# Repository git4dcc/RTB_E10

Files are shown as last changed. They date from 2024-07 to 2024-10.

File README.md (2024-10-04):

# RTB_E10




This E10 module implements a 16 channel WS2811 emulator with compatible bus timing. The E10 may be cascaded with regular WS28xx chips. The number of LEDs is auto detected/configured (0-16). Optionally, the common LED voltage can be controlled over the bus as well.

<details>
<summary>See also</summary>

- [RTB_E13](https://github.com/git4dcc/RTB_E13)
- [RTB_E15](https://github.com/git4dcc/RTB_E15)

</details>

<details>
<summary>User Guides</summary>

- [User Guide - DE](https://rtb4dcc.de/ws2811_guide_de/)
- User Guide - EN

</details>

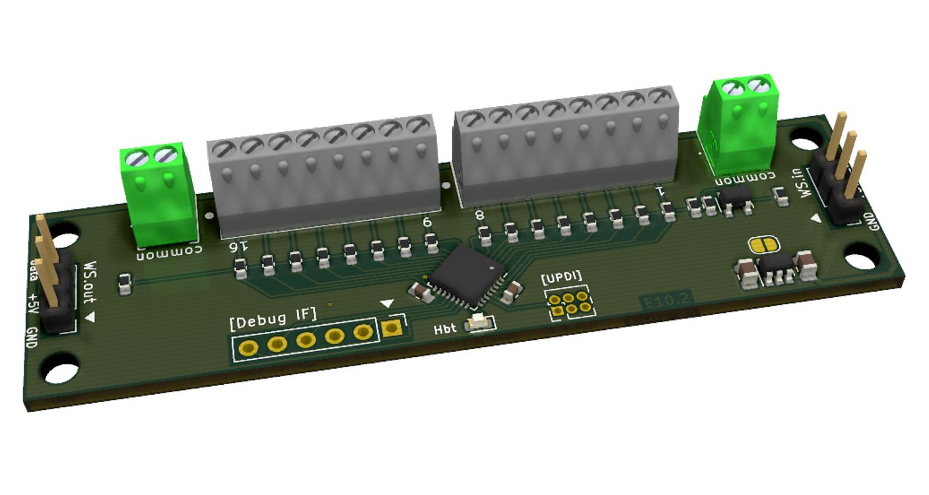
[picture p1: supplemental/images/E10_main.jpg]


The decoder has the following features,
- **Protocol**
  - WS2811 compatible timing
- **LED ports**
  - 0..16 channel output (auto detecting)
  - Software selectable common LED voltage (0 .. 5V)
  - Push/Pull output and can drive common anode or cathode
  - 256 step PWM (240Hz)
  - gamma correction (optional)
- firmware update via V24 debug interface

# Hardware
My current PCB layout uses SMD footprints with 0.5mm pitch and 0603 parts. Reflow soldering is my recommendation, but with some experience handsoldering is also possible.

The hardware allows either push or pull operation. Currently only the pull operation is implemented in the firmware. Should a usecase for push-operation arise, the firmware could be adapted.

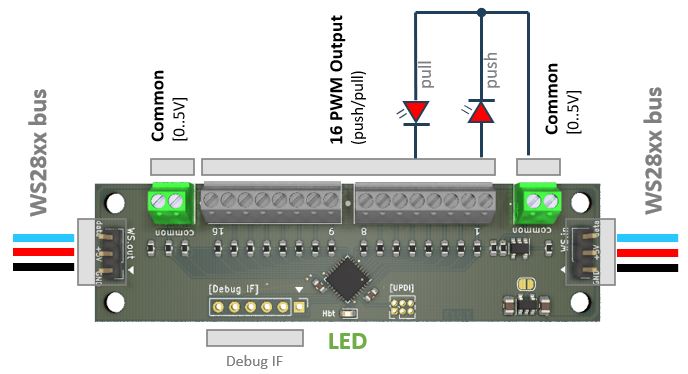
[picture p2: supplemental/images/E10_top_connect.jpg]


## PCB

- 2-layer PCB, FR4, 1.6mm
- CPU: AVR64DA32
- BUS: WS28xx
- LED: Push/Pull

## Kicad
[Schematic](doc/E10_schematic.pdf) | [Layout](doc/E10_layout.pdf) | [Gerber](gerber)

<details>
<summary>Dependency</summary>
<br>

:yellow_circle: Requires my Kicad project library [RTB_SamacSys](https://github.com/git4dcc/RTB_SamacSys) in the same directory tree.

</details>

## Firmware
Filename structure: { **pcb** }{ **code** }{ **version** }.hex

Example: **E10F0001**.hex

| | Description |
| --- | --- |
| **pcb** | Name of matching hardware (**E10**) |
| **code** | Type of code contained (**R**=rom, **B**=bootloader, **F**=flash, **U**=bld update, **P**=UPDI factory code) |
| **version** | Release version (**####**) |

[Firmware files](firmware)

## UPDI
The fuse settings as well as the P-code (E10Pxxxx.hex) has to be installed by using UPDI.<br>

<details>
<summary>Details</summary>

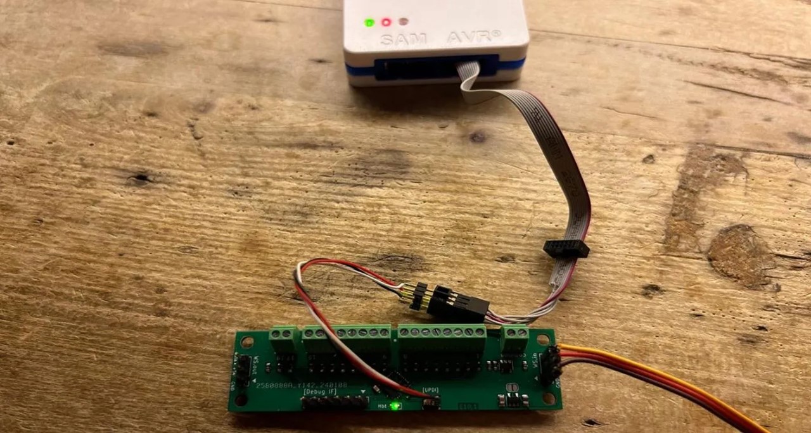
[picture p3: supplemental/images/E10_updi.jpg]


| Fuse Setting | P-Code Install |
| --- | --- |
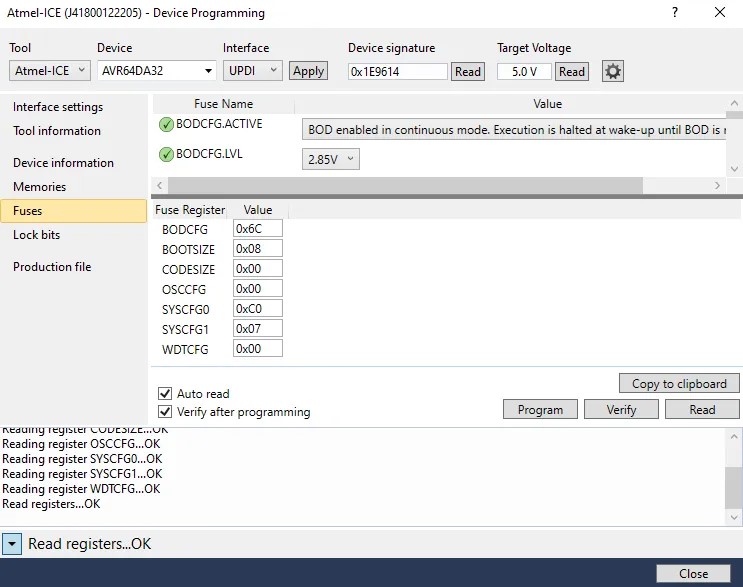
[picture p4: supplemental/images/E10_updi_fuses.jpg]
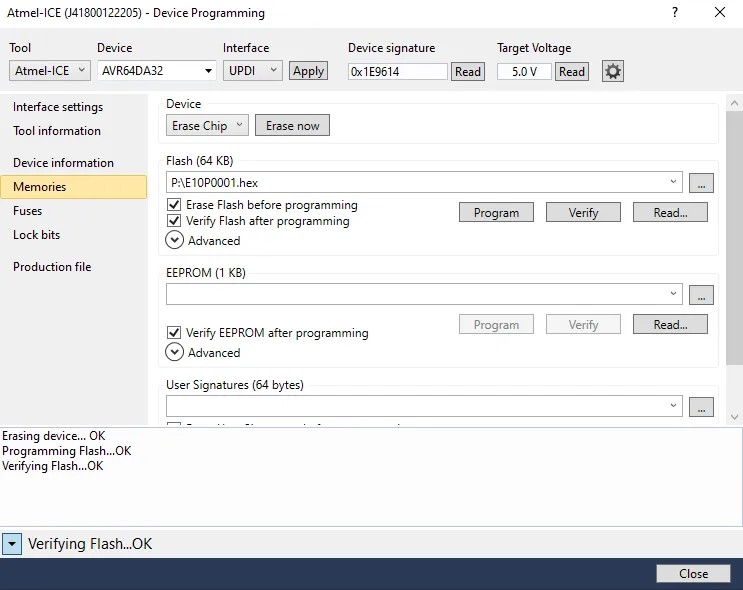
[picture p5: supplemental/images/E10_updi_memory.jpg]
|||

</details>

## Debug Interface
Subsequent code updates can be done via the built-in serial debug interface.<br>

<details>
<summary>Details</summary>

- connect the serial cable **(1Mb, 8N1, RTS/CTS)**
- press 'break' within the VT100 terminal to bump the module to console prompt
- upload the firmware file (E10Fxxxx.hex)
- for more details, refer to the 'User Guide'

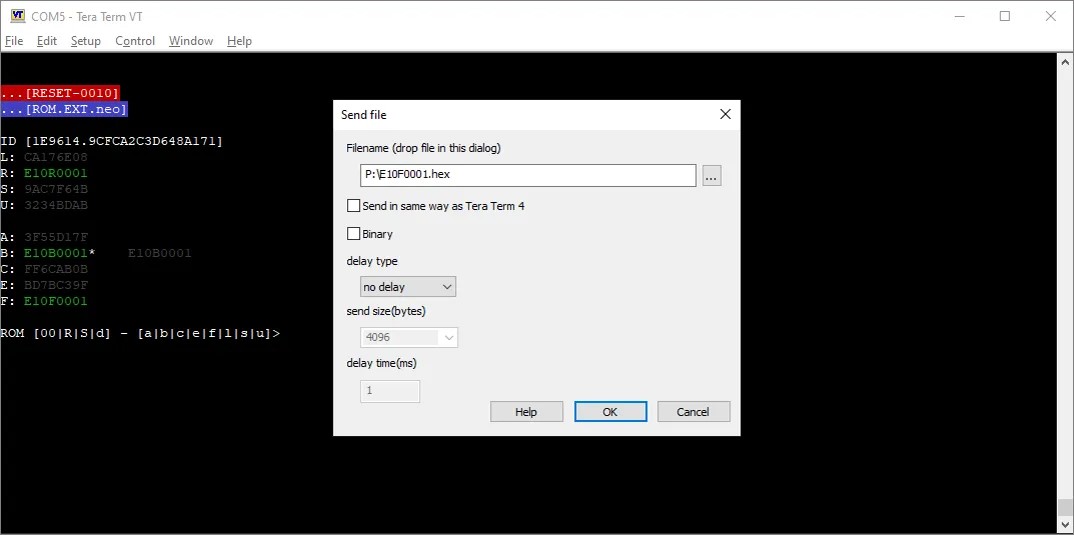
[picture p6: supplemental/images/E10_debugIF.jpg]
  
</details>

# Software
The LED common voltage must be sent as the first byte (virtual LED) over the bus followed by the intensity values for the individual LEDs.

```
Byte order:     {voltage} {led_0} ... {led_n}      //'n' being the number of configured LEDs
Led Voltage:    5V * {voltage} / 255
```

# Images
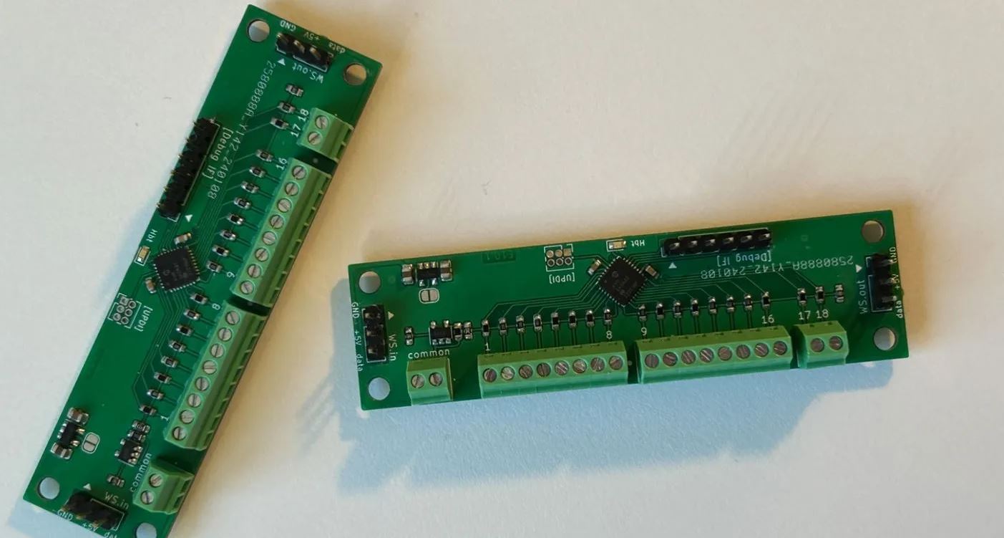
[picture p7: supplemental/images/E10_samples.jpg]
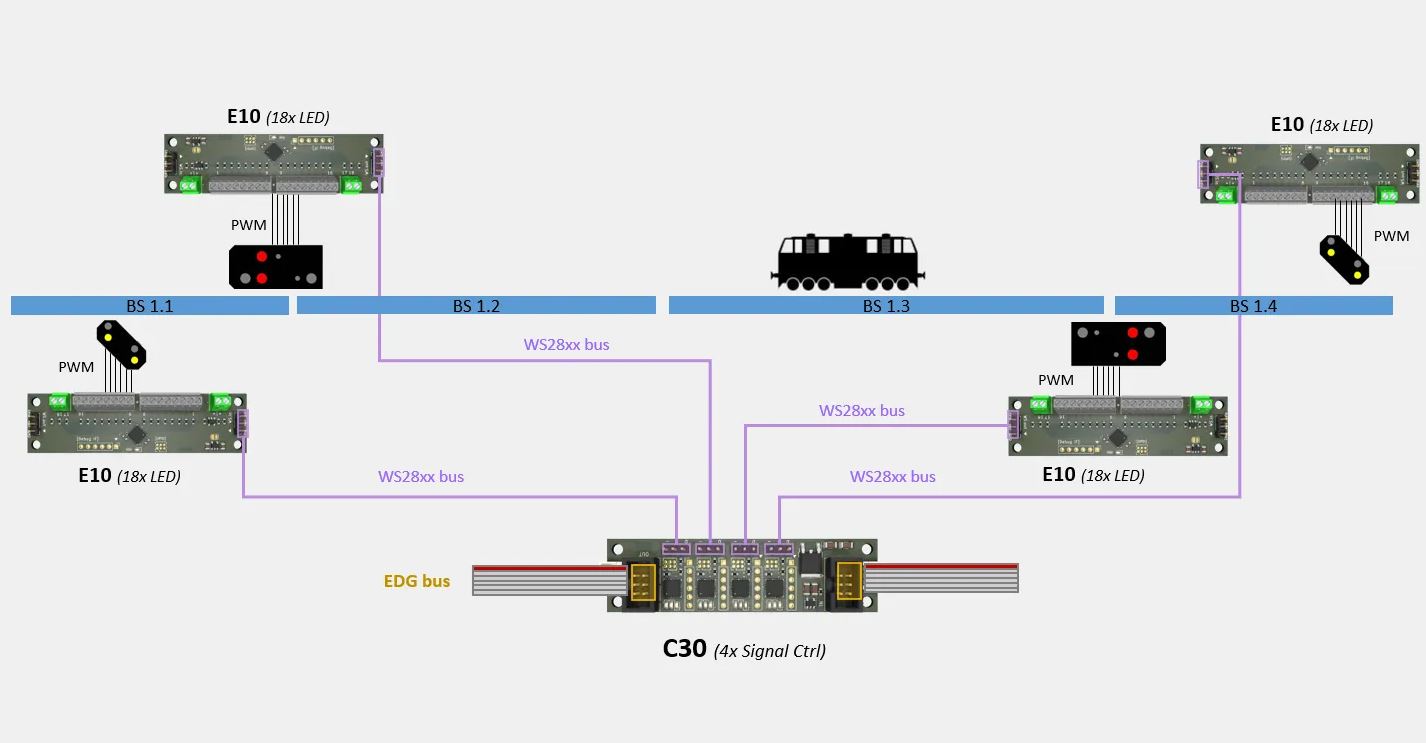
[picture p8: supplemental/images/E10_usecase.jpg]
 

This project is intended for hobby use only and is distributed in accordance with the Apache License 2.0 agreement.

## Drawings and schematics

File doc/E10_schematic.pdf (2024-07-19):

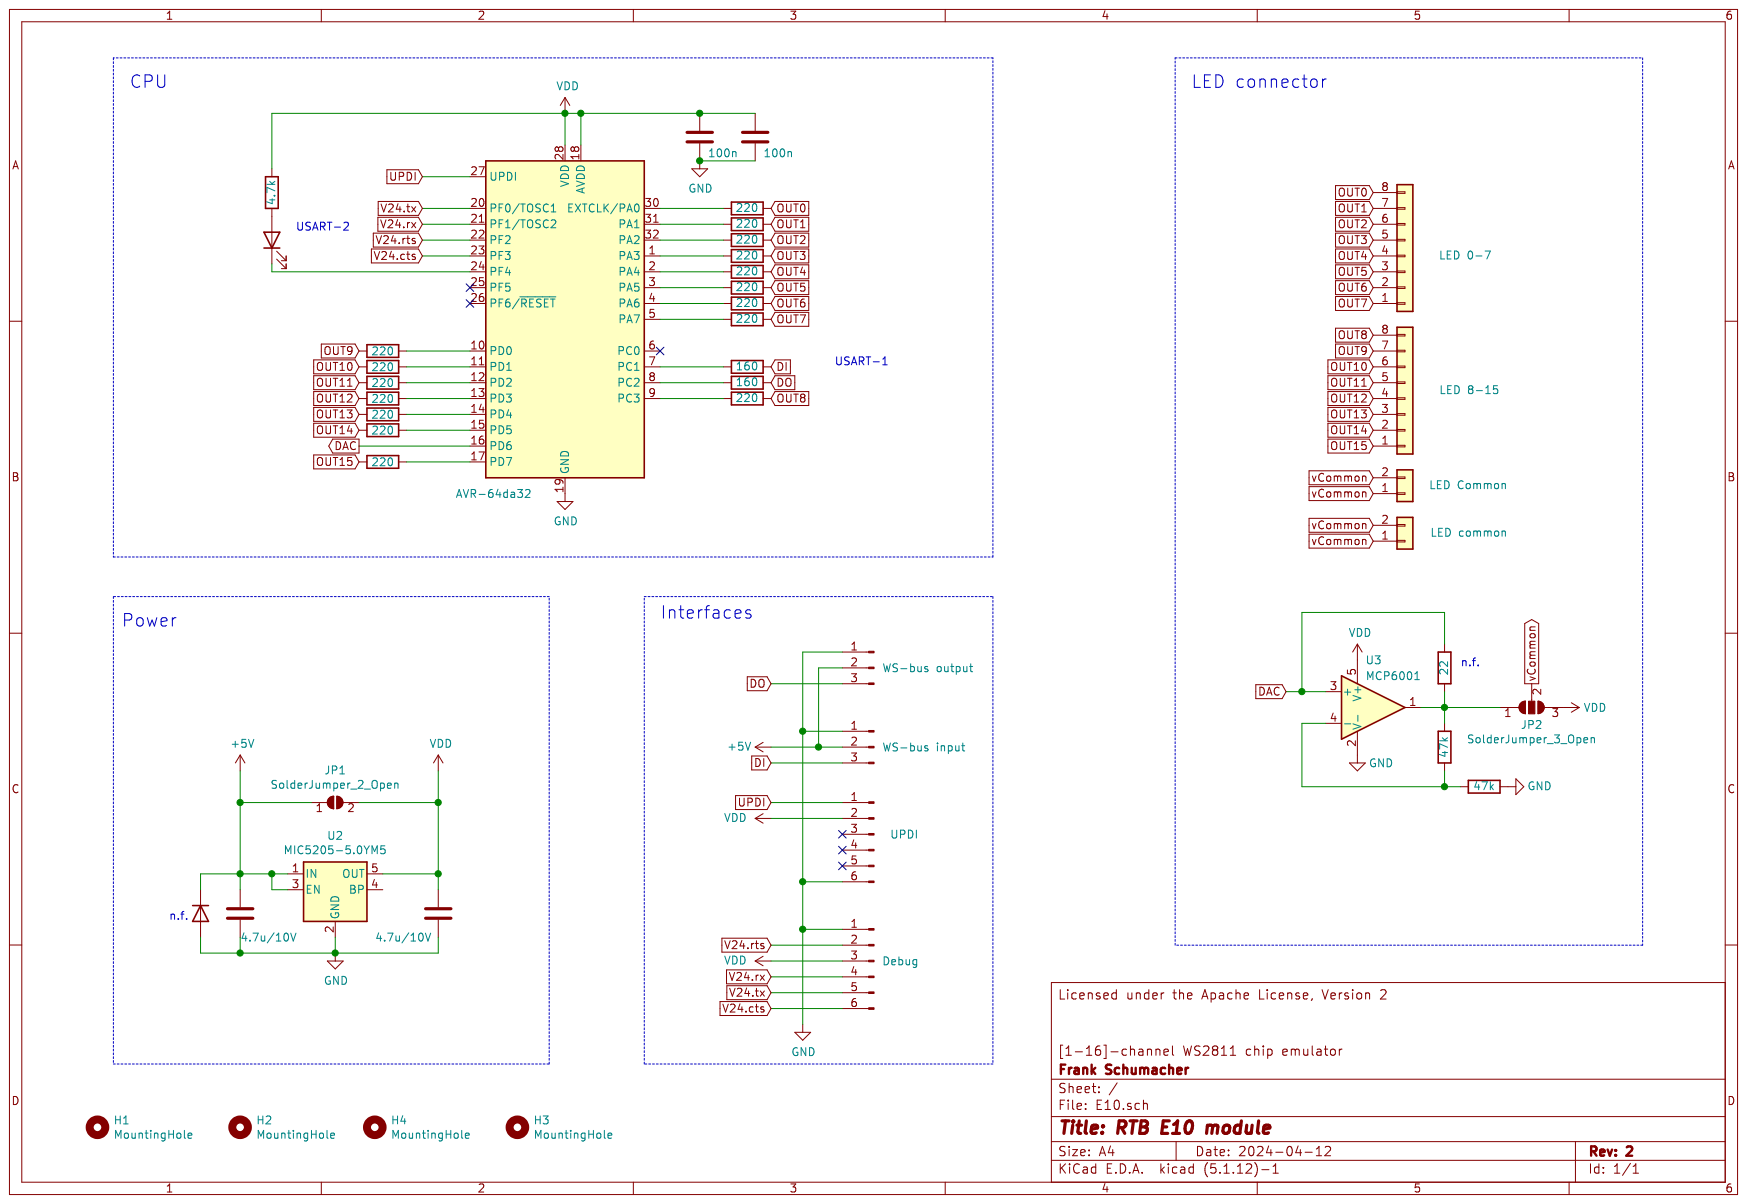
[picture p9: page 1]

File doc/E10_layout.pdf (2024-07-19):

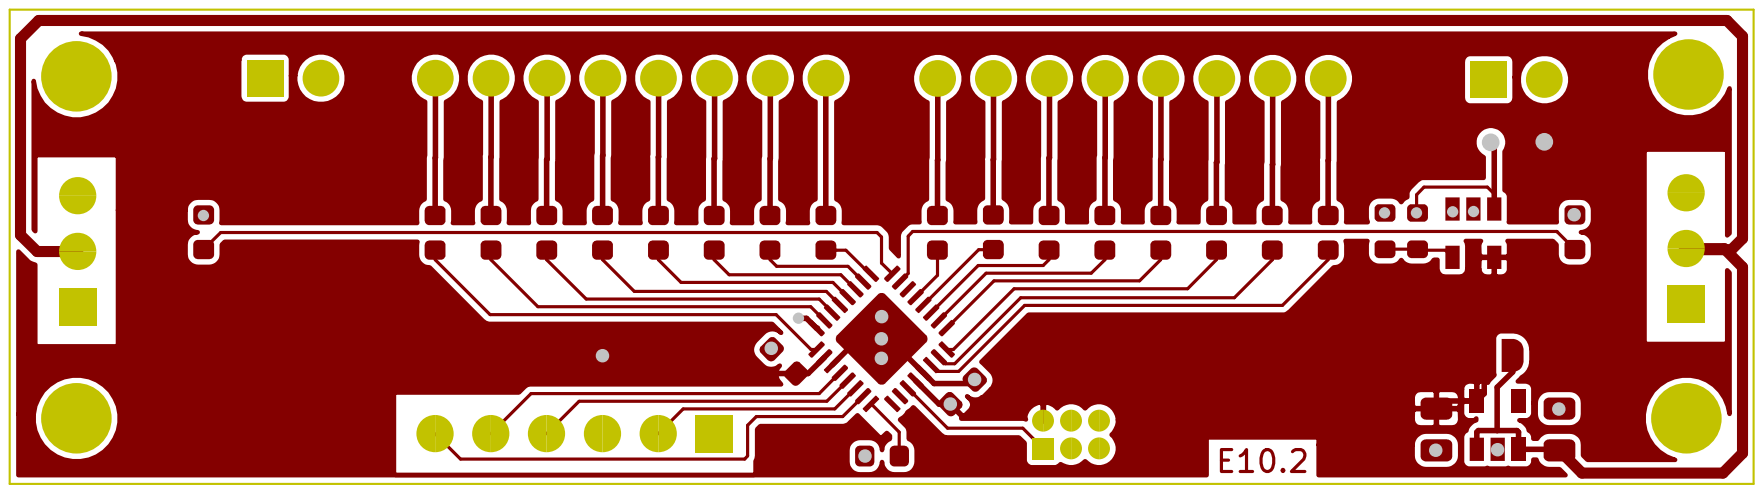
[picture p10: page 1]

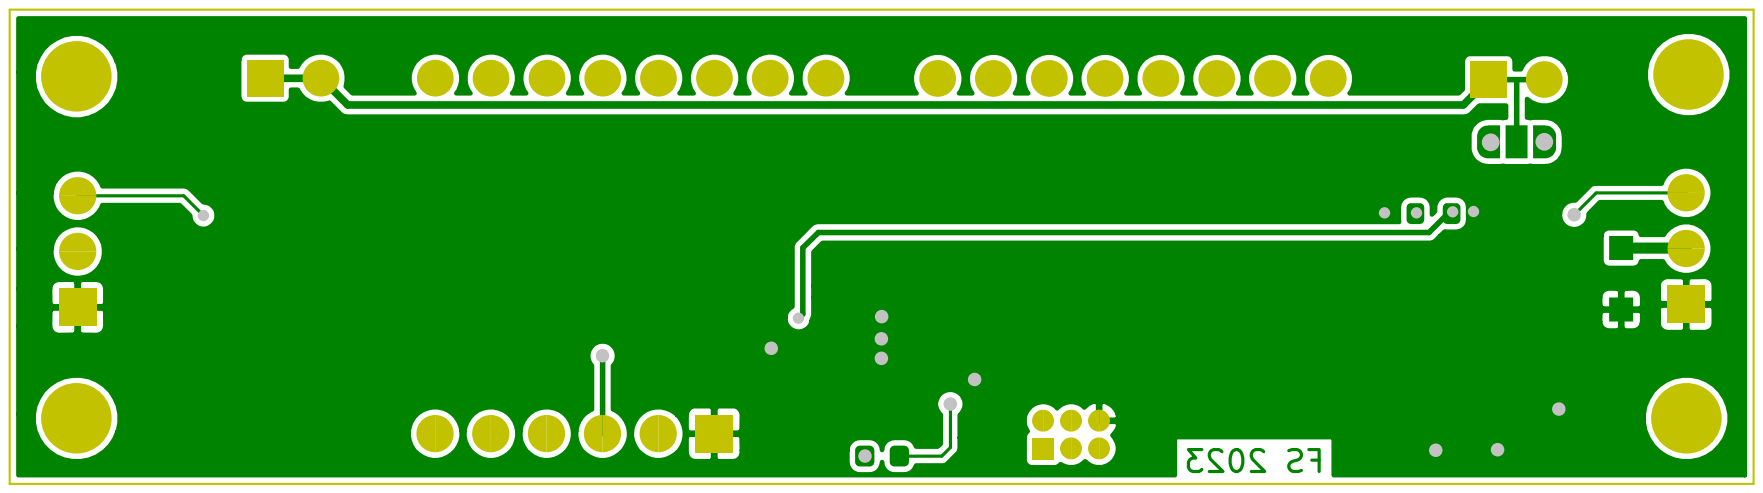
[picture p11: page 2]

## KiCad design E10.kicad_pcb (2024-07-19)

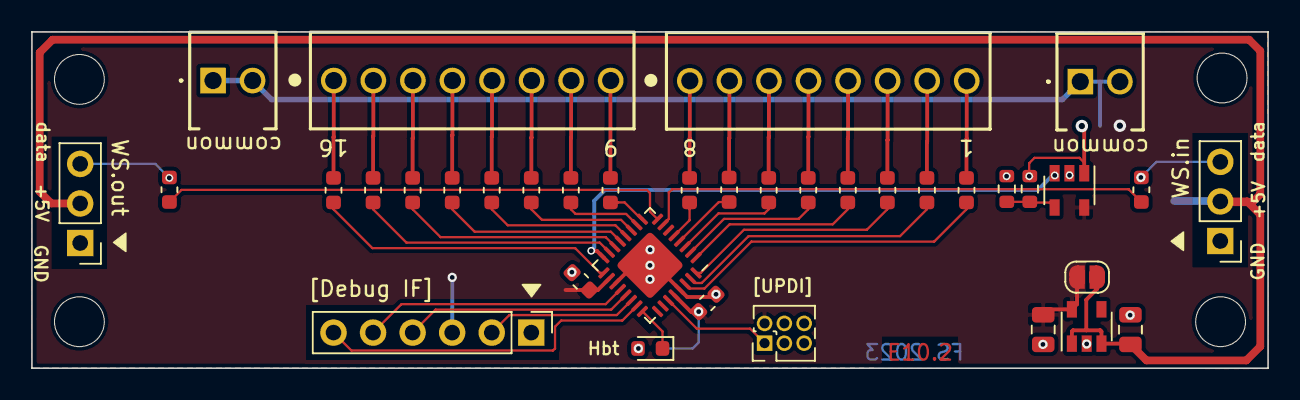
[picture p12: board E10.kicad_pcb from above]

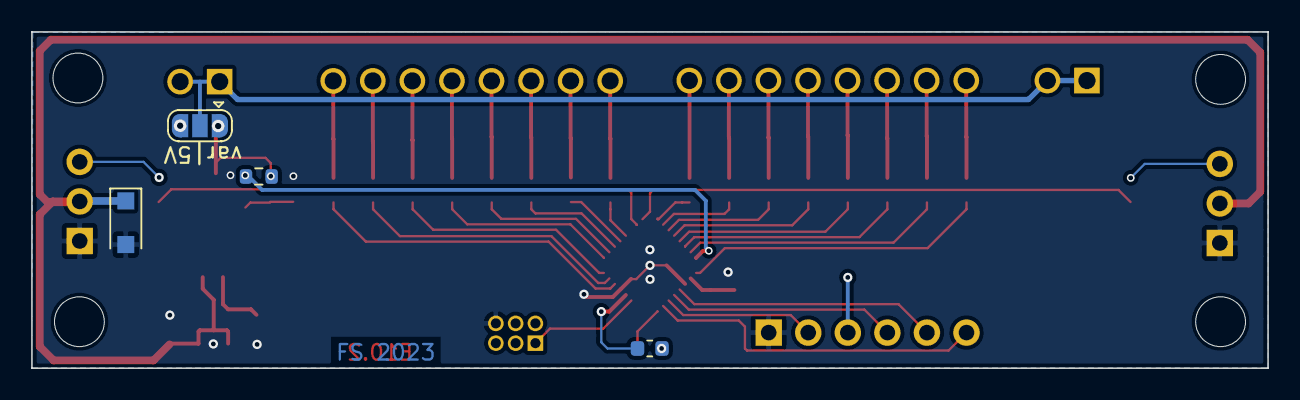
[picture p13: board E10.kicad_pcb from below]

Board: 2 copper layers, 79.4 x 21.6 mm, 45 parts (4 on the bottom side), 50 nets.

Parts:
C1, C4: 4.7u/10V; C_0805_2012Metric
C2, C3: 100n; C_0603_1608Metric
D1: SS34F; D_SOD-123F
D2: HBT(green); LED_0603_1608Metric
H1, H2, H3, H4: MountingHole; MountingHole_3.2mm_M3_DIN965
J1: LED 8-15; 1725711
J2: WS-bus output; PinHeader_1x03_P2.54mm_Vertical
J3: WS-bus input; PinHeader_1x03_P2.54mm_Vertical
J4: UPDI; PinHeader_2x03_P1.27mm_Vertical
J5: Debug; PinHeader_1x06_P2.54mm_Vertical
J6: LED common; 1725656
J7: LED 0-7; 1725711
J8: LED Common; 1725656
JP1: SolderJumper_2_Open; SolderJumper-2_P1.3mm_Open_RoundedPad1.0x1.5mm
JP2: SolderJumper_3_Open; SolderJumper-3_P1.3mm_Open_RoundedPad1.0x1.5mm
R2, R3, R4, R5, R6, R7, R8, R9, R10, R11, R12, R13, R14, R15, R16, R17: 220; R_0603_1608Metric
R18, R19: 160; R_0603_1608Metric
R20: 4.7k; R_0603_1608Metric
R23: 22; R_0603_1608Metric
R24, R25: 47k; R_0603_1608Metric
U1: AVR-64da32; QFN-32-1EP_5x5mm_P0.5mm_EP3.1x3.1mm
U2: MIC5205-5.0YM5; SOT-23-5
U3: MCP6001; SOT-23-5

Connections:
+5V: C1.1, D1.1, J2.2, J3.2, JP1.1, U2.1, U2.3
DAC: R23.2, U1.16, U3.3
DI: J3.3, R18.2
DO: J2.3, R19.2
GND: C1.2, C2.2, C3.2, C4.2, D1.2, J2.1, J3.1, J4.6, J5.1, R25.2, U1.19, U1.29, U1.33, U2.2, U3.2
unnamed: D2.1, U1.24
unnamed: D2.2, R20.1
unnamed: JP2.1, R23.1, R24.2, U3.1
unnamed: R2.1, U1.13
unnamed: R3.1, U1.14
unnamed: R4.1, U1.15
unnamed: R5.1, U1.17
unnamed: R6.1, U1.9
unnamed: R7.1, U1.10
unnamed: R8.1, U1.11
unnamed: R9.1, U1.12
unnamed: R10.1, U1.2
unnamed: R11.1, U1.3
unnamed: R12.1, U1.4
unnamed: R13.1, U1.5
unnamed: R14.1, U1.30
unnamed: R15.1, U1.31
unnamed: R16.1, U1.32
unnamed: R17.1, U1.1
unnamed: R18.1, U1.7
unnamed: R19.1, U1.8
unnamed: R24.1, R25.1, U3.4
OUT0: J7.8, R14.2
OUT1: J7.7, R15.2
OUT2: J7.6, R16.2
OUT3: J7.5, R17.2
OUT4: J7.4, R10.2
OUT5: J7.3, R11.2
OUT6: J7.2, R12.2
OUT7: J7.1, R13.2
OUT8: J1.8, R6.2
OUT9: J1.7, R7.2
OUT10: J1.6, R8.2
OUT11: J1.5, R9.2
OUT12: J1.4, R2.2
OUT13: J1.3, R3.2
OUT14: J1.2, R4.2
OUT15: J1.1, R5.2
UPDI: J4.1, U1.27
V24.cts: J5.6, U1.23
V24.rts: J5.2, U1.22
V24.rx: J5.4, U1.21
V24.tx: J5.5, U1.20
VDD: C2.1, C3.1, C4.1, J4.2, J5.3, JP1.2, JP2.3, R20.2, U1.18, U1.28, U2.5, U3.5
vCommon: J6.1, J6.2, J8.1, J8.2, JP2.2

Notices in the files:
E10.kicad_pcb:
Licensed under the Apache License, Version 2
